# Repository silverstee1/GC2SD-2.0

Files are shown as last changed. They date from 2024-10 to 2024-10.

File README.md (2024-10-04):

# GC2SD-2.0
GC2SD 2.0 Upgrade PCB

Replacement upgrade PCB for GC2SD sold on aliexpress/amazon etc to V2.0 for use on GameCube's Front Memcard Slot B

Based on the SD2SP2 2.0 made by Extrems, Thank you for your hard work!

**Important**

When using the adapter make sure to have the Latest Version of Swiss, Due to the way Swiss handles it in SLOT A it 
acts like a normal speed Passive SDGecko, in SLOT B it works in Semi-Passive 2.0 enhanced speed mode.

https://github.com/emukidid/swiss-gc

20241003_171322-min

20241003_171342-min

20241003_171443-min

20241003_171456-min

GC2SD 2.0 BOM
=====================================
The PCB must be ordered (e.g. from jlcpcb) in 0.8mm thickness with surface finish ENIG at minimum.

**Note**

R1,D1 are not necessary if you don't want to have LED in your adapter or want to minimize on components.

**GC2SD V2.0 PCB**

**R1:** 0402 470ohm Resistor - Digikey Part# 311-470LRCT-ND (you can use smaller value or larger value depending how bright you want it, 14ohm will be the brightest, I choose 470ohm as its what I had on hand and its not too bright)

LCSC Part# C114877

**D1:** 0402 Green Led 20ma (Dot on PCB footprint marks LED Cathode side) - Digikey Part# 1516-1216-1-ND

LCSC Part# C2856703

or

0402 Blue Led 20ma (Dot on PCB footprint marks LED Cathode side) - Digikey Part# 1516-1215-1-ND

LCSC Part # C965797

**J1:** MicroSD Slot - SOFNG TF-004

LCSC Part# C428454

alt LCSC Part# C20624805 , C410348 , C381081

**U1:** OR Gate IC - DigiKey Part# 296-1093-1-ND

LCSC Part# C7470

Alt Nexperia Digikey Part# 1727-3067-1-ND

LCSC Alt Nexperia Part# C12488

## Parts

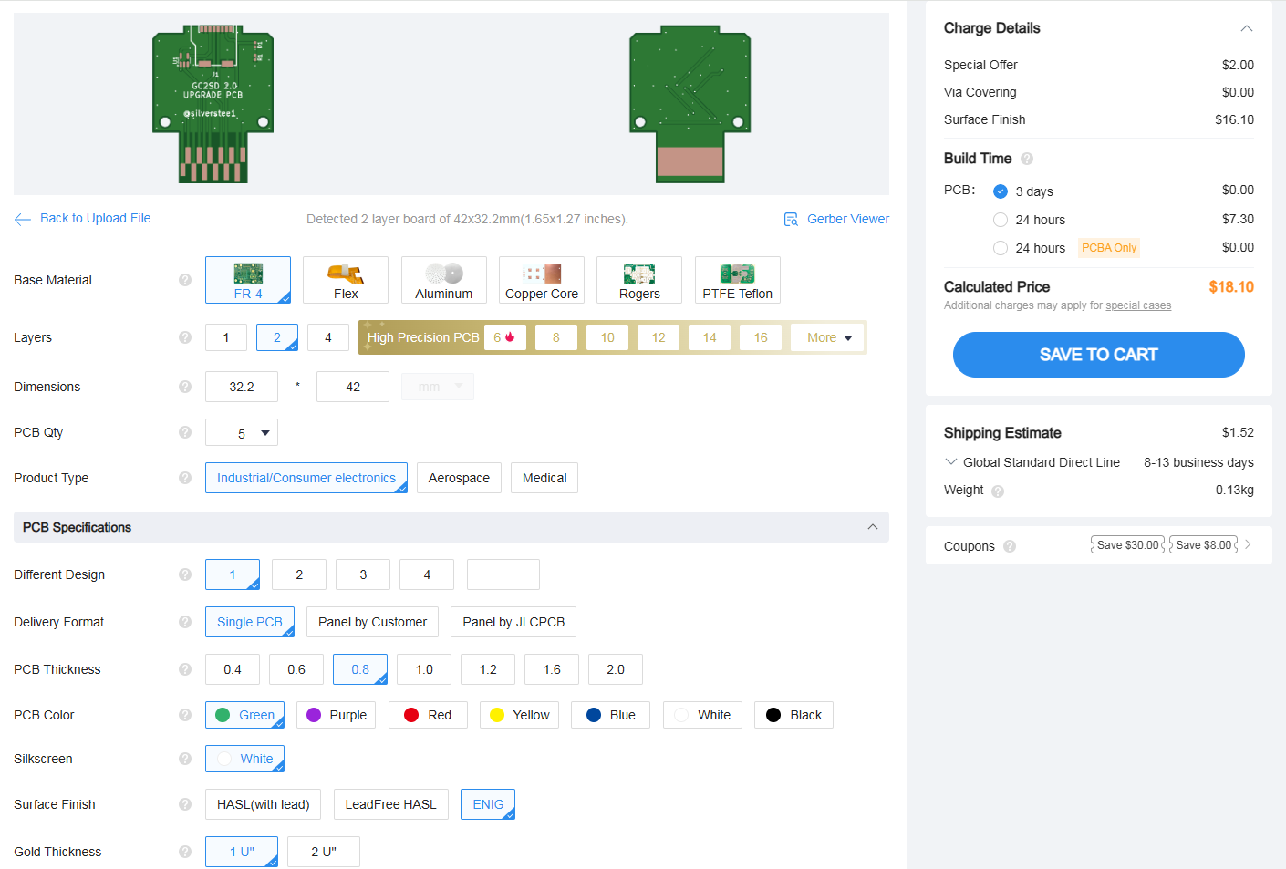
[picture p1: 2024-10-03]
PCB/JLCPCB order example.png

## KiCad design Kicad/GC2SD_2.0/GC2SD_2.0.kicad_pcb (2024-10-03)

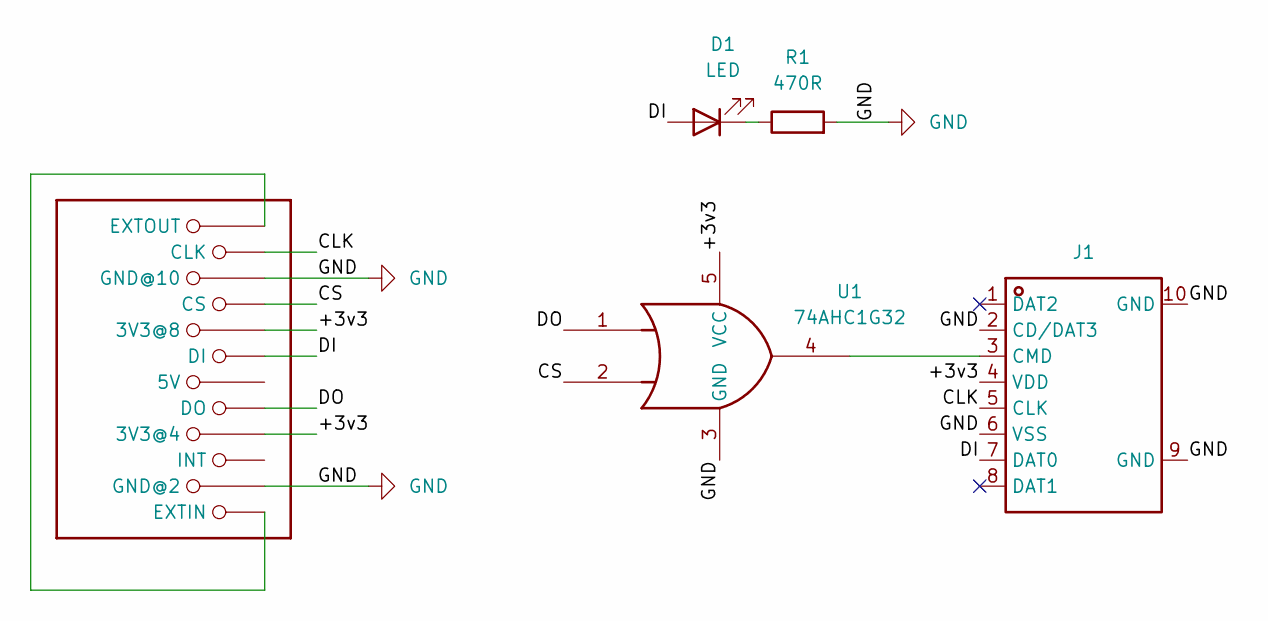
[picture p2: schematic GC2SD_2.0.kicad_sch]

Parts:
D1: LED; LED_0402_1005Metric_Pad0.77x0.64mm_HandSolder
J1: TF-004; TF-SMD_TF-004; MANUFACTURER PART TF-004; LCSC PART NAME 拔插式 MicroSD卡(TF卡) 卡座
J2: GC_MEMCARD
R1: 470R; R_0402_1005Metric_Pad0.72x0.64mm_HandSolder
U1: 74AHC1G32; SC-74A-5_1.55x2.9mm_P0.95mm

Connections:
/+3v3: J1.4 (VDD), J2.4 (3V3@4), J2.8 (3V3@8), U1.5 (VCC)
/CLK: J1.5 (CLK), J2.11 (CLK)
/CS: J2.9 (CS), U1.2
/DI: D1.2 (A), J1.7 (DAT0), J2.7 (DI)
/DO: J2.5 (DO), U1.1
GND: J1.2 (CD/DAT3), J1.6 (VSS), J1.9 (GND), J1.10 (GND), J2.2 (GND@2), J2.10 (GND@10), R1.2, U1.3 (GND)
unnamed: D1.1 (K), R1.1
unnamed: J1.3 (CMD), U1.4
unnamed: J2.1 (EXTIN), J2.12 (EXTOUT)

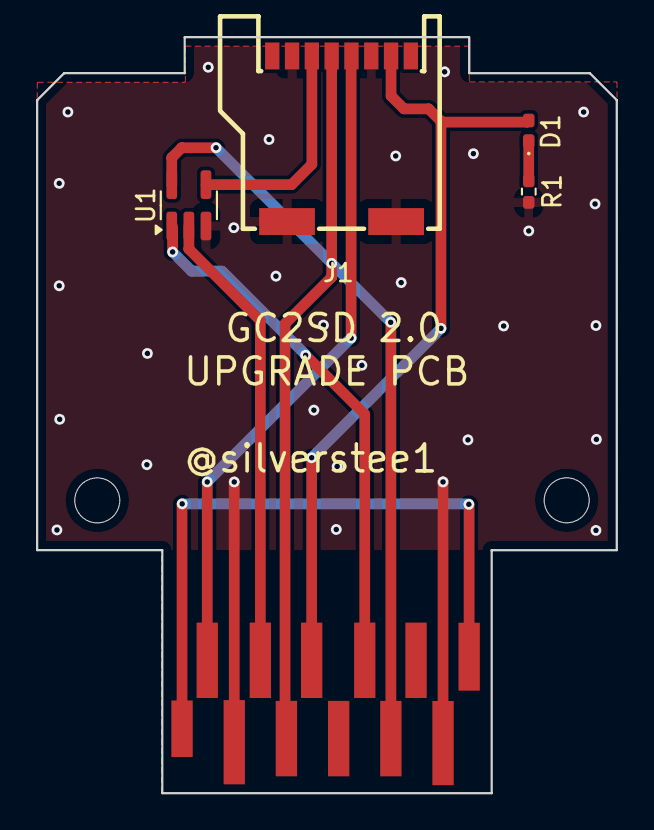
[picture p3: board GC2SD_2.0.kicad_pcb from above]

Board: 2 copper layers, 32.2 x 42.0 mm, 5 parts (0 on the bottom side), 9 nets.

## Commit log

2024-10-03 added project and pcb gerbers
    uploaded project
    [GC2SD_2.0.kicad_pcb, GC2SD_2.0.kicad_sch, TF-0041_TF-004.schdoc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]
2024-10-03 pcb order example
    example of the selected values for pcb order
